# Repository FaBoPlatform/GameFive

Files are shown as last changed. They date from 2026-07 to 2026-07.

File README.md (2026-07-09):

# Game Five

**A handheld game console fully engineered by an AI — Claude "Fable 5"**

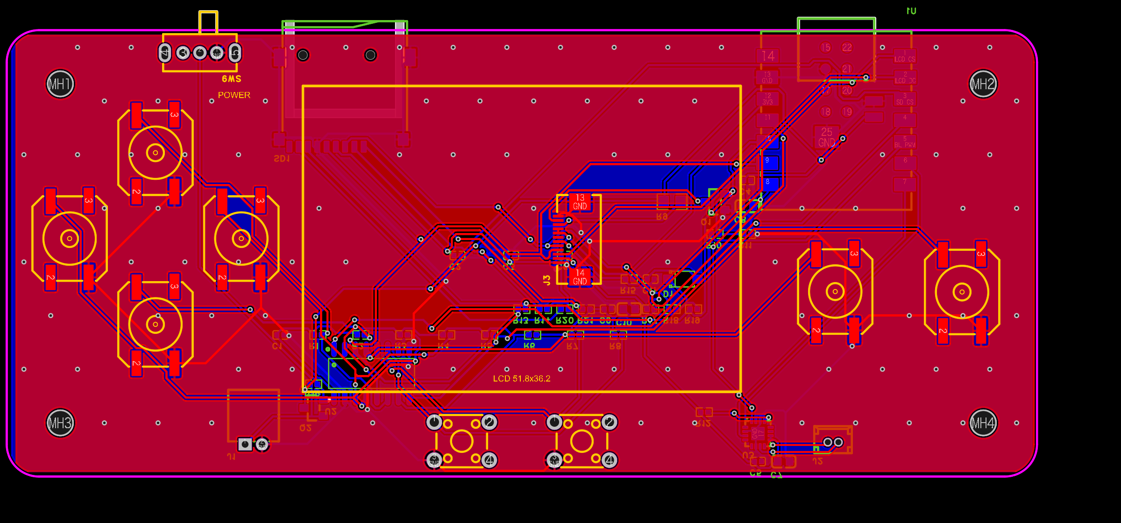
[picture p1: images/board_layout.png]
Game Five PCB (top view)


## About this project

Game Five is an experiment in **end-to-end AI hardware development**. The entire product is designed by **Fable 5** (Anthropic's Claude), directed through natural-language conversation by its human co-designers:

| Deliverable | Developed by Fable 5 | Status |
|---|---|---|
| **Schematic design** | Component selection (all JLCPCB in-stock parts), netlist, power tree, GPIO budgeting via 74HC165 | 🏭 1st prototype in fabrication |
| **PCB layout** | 120 × 61 mm 2-layer board — placement, autorouting, GND pours, stitching vias, DRC clean, fab outputs | 🏭 rev.1 prototype fabricated / rev.2i current (I2S audio restored, battery connector by the D-pad) |
| **Enclosure** | Two-piece 3D-printable case, generated parametrically through the Fusion 360 API | 🚧 In development |
| **Game software** | Board support component + games for ESP32-S3 (display, input, sound drivers) | 🚧 In development — HW test + SNAKE running on the XIAO |

The AI operated the EDA tool (EasyEDA Pro) and the CAD tool (Autodesk Fusion 360) programmatically through their APIs — placing parts, wiring nets, routing, running DRC, exporting Gerbers, and solid-modeling the case — while humans reviewed each iteration and steered the design ("make the D-pad symmetric", "move the display up", "the flat cable folds here").

The hardware itself: a Seeed Studio **XIAO ESP32-S3** driving a 2.0-inch **HS20HS072RX** TFT (ST7789, 240×320, SPI), with GameBoy-style controls and I2S audio.

## Features

- **MCU**: Seeed XIAO ESP32-S3 (Wi-Fi / BLE, USB-C, built-in LiPo charger)
- **Display**: HS20HS072RX 2.0" TFT, 240×320, ST7789, 4-wire SPI (LCSC **C5329582**)
- **Controls**: D-pad + A/B buttons (Panasonic EVQQ1D06M round-plunger tactile switches) + SELECT/START (Omron B3F-1025 through-hole tactile switches — orange round button, crisp 2.55 N click)
- **Audio**: **MAX98357A** I2S mono Class-D amplifier (U3) driving a speaker via a JST 1.25mm 2-pin connector (J2, LCSC **C10819**); SD_MODE pulled up (R12) so the amp is enabled by default, GAIN floated (9 dB)
- **Power**: LiPo battery (JST PH2.0) wired directly to the XIAO BAT± pads — charging is handled by the XIAO's onboard charger
- **Button matrix via 74HC165**: the XIAO exposes only 11 GPIOs, so the 8 buttons are read through a **74HC165** shift register sharing the SPI bus (LCD + buttons + backlight PWM all fit, with I2S pins to spare)
- **PCB**: 120 × 61 mm, 2-layer, ground pours on both sides tied together with ~190 stitching vias, DRC clean
- **Display connector under the panel**: the flat cable folds back at its root (the module's natural fold) and plugs into J3 mounted on the front, underneath the display — a clean rectangular board with no notch and no through-board pass
- **Enclosure**: two-piece 3D-printed case with 1 mm rounded edges — bottom tray with a 10 mm LiPo/speaker cavity and speaker grille, flat solid top cover (print it in clear material so the LCD shows through) with press-through holes for every key (Ø10 mm D-pad/A/B, Ø5 mm SELECT/START); four M2.5 screws pass through the top cover **and the PCB mounting holes** into the bottom bosses, clamping the whole stack together

## Enclosure preview

Two-piece 3D-printable case, solid-modeled parametrically through the Fusion 360 API (1 mm rounded edges, four M2.5 screws clamp top + PCB + bottom as one stack).

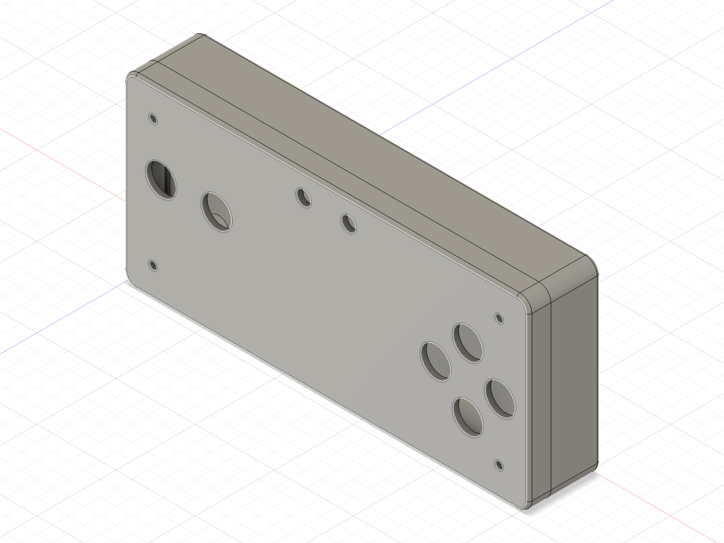
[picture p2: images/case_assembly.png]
Case assembly


| Top cover — Ø10 mm D-pad/A/B holes, Ø5 mm SELECT/START holes, 4× screw through-holes | Bottom tray — 10 mm LiPo/speaker cavity, speaker grille, drop-in USB-C slot, screw bosses |
|---|---|
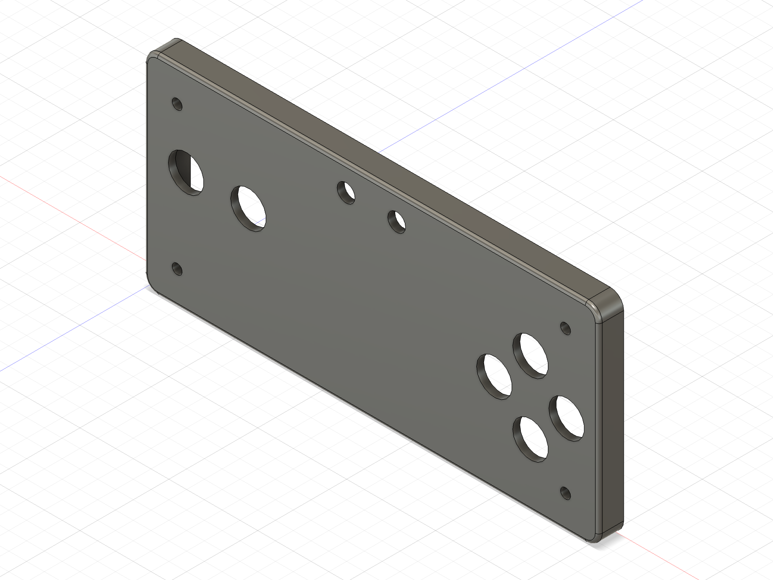
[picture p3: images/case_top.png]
Case top
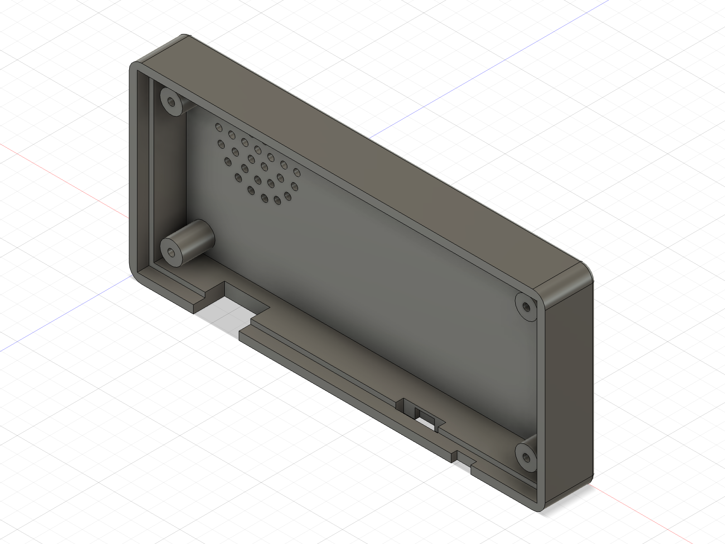
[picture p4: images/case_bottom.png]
Case bottom
|  |  |

## Repository contents

| Path | Contents |
|---|---|
| `fab/GameFive_Gerber.zip` | Gerber files for fabrication (JLCPCB, 2-layer) |
| `fab/GameFive_BOM.xlsx` | Bill of materials with LCSC part numbers (for JLCPCB PCBA) |
| `fab/GameFive_PickAndPlace.xlsx` | Pick-and-place data |
| `case/GameFive_Case_Bottom.stl` / `.step` | Enclosure bottom tray — 10 mm cavity under the PCB for the LiPo + speaker, speaker grille, drop-in USB-C slot |
| `case/GameFive_Case_Top.stl` / `.step` | Enclosure top cover — flat solid deck (clear material recommended), through-holes for all 8 keys |
| `case/case_bottom_fusion360.py` / `case_top_fusion360.py` | Fusion 360 API scripts that regenerate the case parametrically (verification-gated export) |
| `easyeda/GameFive.epro` | **EasyEDA Pro project file** (full schematic + PCB source) — open via File → Open in EasyEDA Pro |
| `firmware/components/gamefive/` | **Board support component** — ST7789 driver, 74HC165 buttons, backlight PWM, pin map, 8×8 font |
| `firmware/hwtest/` | **ESP-IDF hardware bring-up test** — display test patterns + live key test (see its README) |
| `firmware/snake/` | **SNAKE** — the first game (D-pad steer, score, speed-up, high score) |
| `images/` | Board renders |

More games will be added under `firmware/` as development progresses.

## Pin map

| XIAO pin | GPIO | Function |
|---|---|---|
| D0 | GPIO1 | LCD CS |
| D1 | GPIO2 | LCD DC (RS) |
| D2 | GPIO3 | LCD RST |
| D3 | GPIO4 | 74HC165 LATCH (SH/LD#) |
| D4 | GPIO5 | Backlight PWM (SI2302 low-side switch) |
| D5 | GPIO6 | I2S BCLK (MAX98357A) |
| D6 | GPIO43 | I2S LRCLK |
| D7 | GPIO44 | I2S DIN |
| D8 | GPIO7 | SPI SCK (shared by LCD and 74HC165) |
| D9 | GPIO8 | SPI MISO (74HC165 QH) |
| D10 | GPIO9 | SPI MOSI (LCD SDA) |

74HC165 inputs: A=UP, B=DOWN, C=LEFT, D=RIGHT, E=A, F=B, G=START, H=SELECT (10 kΩ pull-ups, active-low).

## Display connection

- The LCD flat cable **folds back at its root** (the module's natural fold, per the datasheet) and plugs into **J3 on the front side, underneath the display** (XKB X05A20L12T, 12-pin 0.5 mm bottom-contact flip connector; mouth toward the module's top edge).
- **J3 is wired in straight pin order** (J3 pin *n* = LCD pin *n*), with the connector rotated 180° to meet the folded tail.
- The silkscreen frame (51.8 × 36.2 mm) on the front marks the display mounting position.
- The display itself (C5329582) is **not included in the BOM** — order it separately.

## Ordering guide (JLCPCB)

1. Upload `fab/GameFive_Gerber.zip` (2-layer, 1.6 mm, any color).
2. For PCBA, upload `GameFive_BOM.xlsx` and `GameFive_PickAndPlace.xlsx`.
3. **U1 (XIAO ESP32-S3) is permanently out of stock at JLC** — either consign the part or mark it DNP and hand-solder it.
4. **J1 (battery connector) and SW7/SW8 (Omron B3F-1025) are through-hole** — not supported by Economic PCBA; use Standard PCBA or hand-solder them.
5. Order the display HS20HS072RX (C5329582) and a LiPo battery separately.
6. 3D-print the case STLs. The case is fastened with four M2.5 screws (~18 mm) that pass through the top cover and the PCB mounting holes into the bottom boss pilot holes — one screw stack holds top, board, and bottom together.

## License

This project is licensed under the **CERN Open Hardware Licence Version 2 – Permissive (CERN-OHL-P-2.0)**.
See [LICENSE](LICENSE) for the full text.

## Credits

- Schematic, PCB layout, enclosure, and game software: **Fable 5** (Claude, Anthropic)
- Co-designed and directed by **Akira & Tom**

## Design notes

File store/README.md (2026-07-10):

# Game Five Store

Games installable over WiFi from the on-device launcher.

## How it works

The launcher (factory partition) fetches `index.txt` from this directory via
GitHub raw, lists the games on screen, and installs the selected one into the
`ota_0` partition (game data goes to the `assets` partition). Hold **B+START
for 2 seconds** inside any game to return to the launcher.

## Index format

One line per game: `id|title|version|bin_url|assets_url|assets_size`
(`assets_url`/`assets_size` empty and 0 when the game has no data file).

## Adding your game

1. Build an ESP-IDF app for the XIAO ESP32-S3 using the shared
   `firmware/launcher/partitions.csv` table (app must fit the 2MB `ota_0`
   slot) and the `gamefive` BSP component.
2. Add the B+START exit combo (see `firmware/snake/main/main.c`).
3. Put the built `.bin` here and add a line to `index.txt` via pull request.
   Games written with AI assistance are very welcome — this whole console is
   an AI-development experiment.

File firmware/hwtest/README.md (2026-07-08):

# Game Five — hardware bring-up test (`hwtest`)

ESP-IDF firmware that exercises the Game Five board: the ST7789 display and
all eight buttons. Flash this first on a freshly assembled prototype.

## What it does

1. **Display test** (runs automatically at boot)
   - backlight PWM fade-in
   - full-screen fills: RED → GREEN → BLUE → WHITE → BLACK (each labeled)
   - 8 color bars, 32-step grayscale gradient, 8 px checkerboard
   - 1 px border + crosshair + colored corner markers (edge alignment check)
   - "GAME FIVE" splash
2. **Key test** (runs forever afterwards)
   - on-screen indicators for UP/DOWN/LEFT/RIGHT/A/B/START/SELECT that
     light up while pressed
   - raw 74HC165 byte shown in hex + binary (for wiring bring-up)
   - every edge logged over USB serial (`idf.py monitor`)
   - hold **SELECT + START for 1.5 s** to re-run the display test

## Build & flash

```bash
. ~/.espressif/v6.0.1/esp-idf/export.sh   # or your ESP-IDF v5.3+/v6 install
cd firmware/hwtest
idf.py set-target esp32s3
idf.py -p /dev/cu.usbmodem*  flash monitor   # XIAO's USB-C (native USB)
```

## Bring-up notes

- **Colors inverted** (RED shows as CYAN)? Set `GF_LCD_INVERT 1` in
  `main/gamefive_pins.h`.
- **Image upside down**? Set `GF_LCD_ROTATE_180 0`.
- **Wrong keys light up**? The raw binary line at the bottom shows the shift
  register byte directly (bit7 = input H = SELECT … bit0 = input A = UP,
  0 = pressed); adjust the mapping in `main/keys.h` to match.
- All pins are defined in one place: `main/gamefive_pins.h`.

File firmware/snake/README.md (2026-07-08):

# Game Five — SNAKE

The first game for Game Five: classic snake on a 30×37 grid.

- **D-pad** — steer
- **START / A** — start, retry, pause (START)
- **SELECT (hold 1.5 s)** — back to the title screen
- Eat food to grow; every food speeds the snake up a little.
- Session high score shown on the HUD and title screen.

## Build & flash

```bash
. ~/.espressif/v6.0.1/esp-idf/export.sh
cd firmware/snake
idf.py set-target esp32s3
idf.py -p /dev/cu.usbmodem* flash monitor
```

Board support (display, buttons, backlight, pins) lives in the shared
component [`firmware/components/gamefive`](../components/gamefive).

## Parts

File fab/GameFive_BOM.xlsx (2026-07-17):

Supplier | Supplier Part | Manufacturer | Manufacturer Part | Value | Footprint | Designator | Comment | Quantity | No.
LCSC | CL05B104KO5NNNC.1 | SAMSUNG(三星) | CL05B104KO5NNNC |  | C0402 | C1,C3,C5,C6 | CL05B104KO5NNNC | 4 | 1
LCSC | CL05A105KA5NQNC.1 | SAMSUNG(三星) | CL05A105KA5NQNC |  | C0402 | C2,C4 | CL05A105KA5NQNC | 2 | 2
LCSC | CL10A106KP8NNNC.1 | SAMSUNG(三星) | CL10A106KP8NNNC |  | C0603 | C7,C8 | CL10A106KP8NNNC | 2 | 3
LCSC | C1525 | SAMSUNG(三星) | CL05B104KO5NNNC |  | C0402 | C9 | CL05B104KO5NNNC | 1 | 4
LCSC | C19702 | SAMSUNG(三星) | CL10A106KP8NNNC |  | C0603 | C10 | CL10A106KP8NNNC | 1 | 5
LCSC | C52923 | SAMSUNG(三星) | CL05A105KA5NQNC |  | C0402 | C11 | CL05A105KA5NQNC | 1 | 6
LCSC | C81598 | ST(先科) | 1N4148W |  | SOD-123F_L2.7-W1.6-LS3.8-RD | D1 | 1N4148W | 1 | 7
LCSC | KH-PH-2P-W.1 | kinghelm(金航标) | KH-PH-2P-W |  | CONN-TH_2P-P2.00_KINGHELM_KH-PH-2P-W | J1 | KH-PH-2P-W | 1 | 8
LCSC | C10819 | BOOMELE | 1.25T-2A |  | CONN-TH_1.25T-1-2A | J2 | 1.25T-2A | 1 | 9
LCSC | X05A20L12T.1 | XKB Connection(中国星坤) | X05A20L12T |  | FFC-SMD_12P-P0.50_X05A20L12T | J3 | X05A20L12T | 1 | 10
LCSC | SI2302_C2938373.1 | GOODWORK(固得沃克) | SI2302 |  | SOT-23_L2.9-W1.3-P1.90-LS2.4-BR | Q1 | SI2302 | 1 | 11
LCSC | C15127 | AOS | AO3401A |  | SOT-23_L2.9-W1.3-P1.90-LS2.4-BR | Q2 | AO3401A | 1 | 12
LCSC | C191123 | PANASONIC | ERJ2RKF1002X |  | R0402 | R1,R2,R3,R4,R5,R6,R7,R8 | ERJ2RKF1002X | 8 | 13
LCSC | 0805W8F220JT5E.1 | UNI-ROYAL(厚声) | 0805W8F220JT5E |  | R0805 | R9 | 0805W8F220JT5E | 1 | 14
LCSC | 0402WGF1000TCE.1 | UNI-ROYAL(厚声) | 0402WGF1000TCE |  | R0402 | R10 | 0402WGF1000TCE | 1 | 15
LCSC | 0402WGF1003TCE.1 | UNI-ROYAL(厚声) | 0402WGF1003TCE |  | R0402 | R11 | 0402WGF1003TCE | 1 | 16
LCSC | C25741 | UNI-ROYAL(厚声) | 0402WGF1003TCE |  | R0402 | R12,R16 | 0402WGF1003TCE | 2 | 17
LCSC | C11702 | UNI-ROYAL(厚声) | 0402WGF1001TCE |  | R0402 | R13 | 0402WGF1001TCE | 1 | 18
LCSC | C191123 | PANASONIC(松下) | ERJ2RKF1002X |  | R0402 | R14,R15,R17,R18,R19,R20,R21 | ERJ2RKF1002X | 7 | 19
LCSC | C91145 | 韩国韩荣 | TF-01A |  | TF-SMD_TF-01A | SD1 | TF-01A | 1 | 20
LCSC | EVQQ1D06M.1 | PANASONIC(松下) | EVQQ1D06M |  | SW-SMD_4P-L10.0-W8.6-P4.50-LS10.0 | SW1,SW2,SW3,SW4,SW5,SW6 | EVQQ1D06M | 6 | 21
LCSC | B3F-1025.1 | OMRON(欧姆龙) | B3F-1025 |  | SW-TH_4P-L6.2-W6.2-P4.50-LS6.5 | SW7,SW8 | B3F-1025 | 2 | 22
LCSC | C2681575 | SHOU HAN | SK12D07VG6 |  | SW-TH_SK12D07VG4 | SW9 | SK12D07VG6 | 1 | 23
LCSC | C9900154951 | JLCPCB | XIAO ESP32S3 |  | COMM-SMD_L21.1-W17.8-P2.54_113991114_XIAO-ESP32-S3 | U1 | XIAO ESP32S3 | 1 | 24
LCSC | SN74HC165DR.1 | TI(德州仪器) | SN74HC165DR |  | SOP-16_L10.0-W3.9-P1.27-LS6.0-BL | U2 | SN74HC165DR | 1 | 25
LCSC | C910544 | Analog Devices | MAX98357AETE+T |  | TQFN-16_L3.0-W3.0-P0.50-BL-EP1.5 | U3 | MAX98357AETE+T | 1 | 26

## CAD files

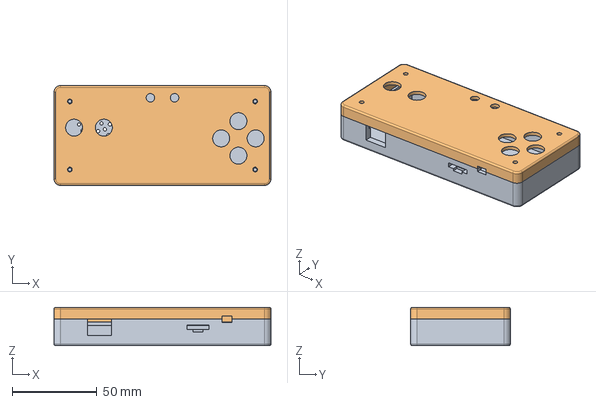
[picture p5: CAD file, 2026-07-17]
case/GameFive_Case_Assembly.step
127.9 x 58.8 x 22.6 mm

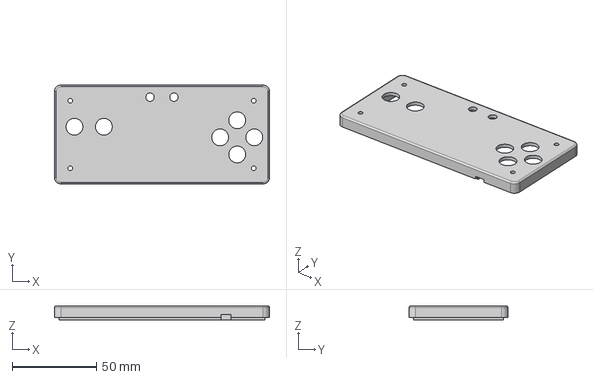
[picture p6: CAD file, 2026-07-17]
case/GameFive_Case_Top.step
127.9 x 58.8 x 8.50 mm

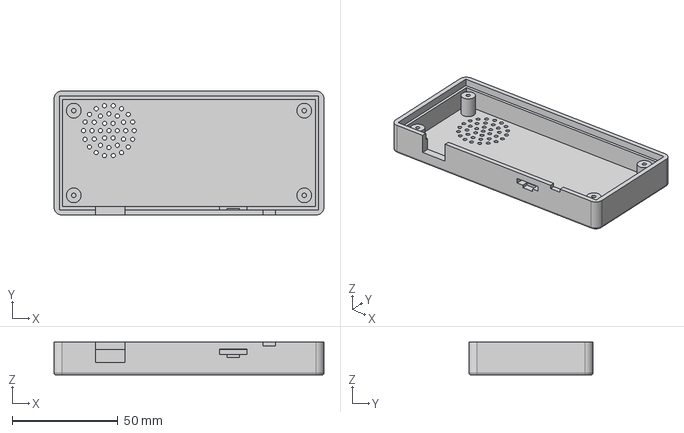
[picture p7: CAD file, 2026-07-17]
case/GameFive_Case_Bottom.step
127.9 x 58.8 x 15.6 mm

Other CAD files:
case/GameFive_Case_Bottom.stl
case/GameFive_Case_Top.stl

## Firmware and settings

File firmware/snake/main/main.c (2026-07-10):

/*
 * Game Five — SNAKE
 *
 * Controls:
 *   D-pad ......... steer
 *   START ......... start game / pause
 *   A ............. start game / restart after game over
 *   SELECT (hold) . back to title
 *
 * SPDX-License-Identifier: CERN-OHL-P-2.0
 */
#include <stdio.h>
#include <string.h>
#include "freertos/FreeRTOS.h"
#include "freertos/task.h"
#include "esp_log.h"
#include "esp_random.h"
#include "esp_system.h"
#include "esp_ota_ops.h"
#include "esp_partition.h"

#include "gamefive_pins.h"
#include "lcd.h"
#include "keys.h"

static const char *TAG = "snake";

/*
 * Old-prototype compatibility (HandyGame rev.0 board): the UP (bit0) and
 * SELECT (bit7) shift-register lines are stuck low on that board, so they
 * are masked out, the A button steers UP, and holding B returns to the
 * title screen. Set to 0 for the Game Five rev.1 board.
 */
#define SNAKE_OLDBOARD_COMPAT 1

#if SNAKE_OLDBOARD_COMPAT
#define KEYS_IGNORE_MASK ((uint8_t)(GF_KEY_UP | GF_KEY_SELECT))
#define TITLE_HOLD_KEY   GF_KEY_B
#else
#define KEYS_IGNORE_MASK ((uint8_t)0)
#define TITLE_HOLD_KEY   GF_KEY_SELECT
#endif

#define W GF_LCD_H_RES            /* 240 */
#define H GF_LCD_V_RES            /* 320 */

#define CELL      8
#define HUD_H     24
#define COLS      (W / CELL)              /* 30 */
#define ROWS      ((H - HUD_H) / CELL)    /* 37 */
#define FIELD_Y   HUD_H
#define MAX_LEN   (COLS * ROWS)

#define TICK_MS          20
#define STEP_START_MS    180
#define STEP_MIN_MS      70
#define STEP_ACCEL_MS    5     /* faster by this much per food */

typedef struct { int8_t x, y; } cell_t;

typedef enum { DIR_UP, DIR_DOWN, DIR_LEFT, DIR_RIGHT } dir_t;

static const int8_t k_dx[] = { 0, 0, -1, 1 };
static const int8_t k_dy[] = { -1, 1, 0, 0 };

/* snake body as a ring buffer of cells; head_i points at the head */
static cell_t s_body[MAX_LEN];
static int s_head_i, s_len;
/* occupancy grid for O(1) self-collision + food placement */
static uint8_t s_occ[COLS][ROWS];

static uint32_t s_score, s_hiscore;

static inline cell_t body_at(int back)   /* back=0 → head */
{
    int i = s_head_i - back;
    while (i < 0) i += MAX_LEN;
    return s_body[i % MAX_LEN];
}

static void cell_fill(cell_t c, uint16_t color)
{
    gf_lcd_fill_rect(c.x * CELL, FIELD_Y + c.y * CELL, CELL, CELL, color);
}

static void draw_snake_cell(cell_t c, bool head)
{
    int x = c.x * CELL, y = FIELD_Y + c.y * CELL;
    gf_lcd_fill_rect(x, y, CELL, CELL, head ? GF_GREEN : GF_RGB(0, 180, 0));
    gf_lcd_fill_rect(x + 1, y + 1, CELL - 2, CELL - 2,
                     head ? GF_RGB(160, 255, 160) : GF_GREEN);
}

static void draw_food(cell_t c)
{
    int x = c.x * CELL, y = FIELD_Y + c.y * CELL;
    gf_lcd_fill_rect(x + 1, y + 1, CELL - 2, CELL - 2, GF_RED);
    gf_lcd_fill_rect(x + 2, y + 2, 2, 2, GF_ORANGE);
}

static void hud_draw(void)
{
    char buf[24];
    gf_lcd_fill_rect(0, 0, W, HUD_H, GF_BLACK);
    gf_lcd_fill_rect(0, HUD_H - 2, W, 2, GF_ORANGE);
    snprintf(buf, sizeof(buf), "SCORE %lu", (unsigned long)s_score);
    gf_lcd_text(6, 4, buf, 2, GF_WHITE, GF_BLACK);
    snprintf(buf, sizeof(buf), "HI %lu", (unsigned long)s_hiscore);
    gf_lcd_text(W - 6 - gf_lcd_text_w(buf, 1), 8, buf, 1, GF_GRAY, GF_BLACK);
}

static cell_t food_place(void)
{
    cell_t c;
    do {
        c.x = (int8_t)(esp_random() % COLS);
        c.y = (int8_t)(esp_random() % ROWS);
    } while (s_occ[c.x][c.y]);
    draw_food(c);
    return c;
}

/* ---- back-to-launcher combo: hold B+START ~2s (works on all boards) ---- */
static void check_exit_combo(uint8_t held)
{
    static int count;
    if ((held & (GF_KEY_B | GF_KEY_START)) == (GF_KEY_B | GF_KEY_START)) {
        if (++count >= 2000 / TICK_MS) {
            const esp_partition_t *factory = esp_partition_find_first(
                ESP_PARTITION_TYPE_APP, ESP_PARTITION_SUBTYPE_APP_FACTORY, NULL);
            if (factory && esp_ota_set_boot_partition(factory) == ESP_OK)
                esp_restart();
        }
    } else {
        count = 0;
    }
}

/* ---- key edge helper ---- */
static uint8_t s_prev_keys;
static uint8_t keys_pressed_edges(uint8_t *held_out)
{
    uint8_t now = gf_keys_read(NULL) & (uint8_t)~KEYS_IGNORE_MASK;
    uint8_t edges = (uint8_t)(now & ~s_prev_keys);
    s_prev_keys = now;
    if (held_out) *held_out = now;
    check_exit_combo(now);
    return edges;
}

/* ---------------------------------------------------------------- title */

static void title_screen(void)
{
    gf_lcd_clear(GF_BLACK);
    gf_lcd_rect(6, 6, W - 12, H - 12, 2, GF_GREEN);
    gf_lcd_text((W - gf_lcd_text_w("SNAKE", 6)) / 2, 80, "SNAKE", 6,
                GF_GREEN, GF_BLACK);

    /* little snake + food doodle */
    for (int i = 0; i < 7; i++) {
        cell_t c = { (int8_t)(8 + i), 18 };
        draw_snake_cell(c, i == 6);
    }
    draw_food((cell_t){ 18, 18 });

    gf_lcd_text((W - gf_lcd_text_w("PRESS START", 2)) / 2, 210,
                "PRESS START", 2, GF_WHITE, GF_BLACK);
#if SNAKE_OLDBOARD_COMPAT
    gf_lcd_text((W - gf_lcd_text_w("A=UP  HOLD B=TITLE", 1)) / 2, 236,
                "A=UP  HOLD B=TITLE", 1, GF_GRAY, GF_BLACK);
#endif
    char buf[24];
    snprintf(buf, sizeof(buf), "HI SCORE %lu", (unsigned long)s_hiscore);
    gf_lcd_text((W - gf_lcd_text_w(buf, 1)) / 2, 250, buf, 1,
                GF_GRAY, GF_BLACK);
    gf_lcd_text((W - gf_lcd_text_w("GAME FIVE", 1)) / 2, 300, "GAME FIVE", 1,
                GF_DKGRAY, GF_BLACK);

    ESP_LOGI(TAG, "title screen");
    for (;;) {
        uint8_t edges = keys_pressed_edges(NULL);
        if (edges & (GF_KEY_START | GF_KEY_A)) return;
        vTaskDelay(pdMS_TO_TICKS(TICK_MS));
    }
}

/* ----------------------------------------------------------------- game */

static void game_over(void)
{
    ESP_LOGI(TAG, "game over, score=%lu", (unsigned long)s_score);
    if (s_score > s_hiscore) s_hiscore = s_score;

    /* flash the snake */
    for (int f = 0; f < 4; f++) {
        for (int i = 0; i < s_len; i++) {
            cell_fill(body_at(i), (f & 1) ? GF_GREEN : GF_RED);
        }
        vTaskDelay(pdMS_TO_TICKS(150));
    }

    int bw = 200, bh = 96;
    int bx = (W - bw) / 2, by = (H - bh) / 2;
    gf_lcd_fill_rect(bx, by, bw, bh, GF_BLACK);
    gf_lcd_rect(bx, by, bw, bh, 2, GF_RED);
    gf_lcd_text(bx + (bw - gf_lcd_text_w("GAME OVER", 2)) / 2, by + 14,
                "GAME OVER", 2, GF_RED, GF_BLACK);
    char buf[24];
    snprintf(buf, sizeof(buf), "SCORE %lu", (unsigned long)s_score);
    gf_lcd_text(bx + (bw - gf_lcd_text_w(buf, 2)) / 2, by + 44, buf, 2,
                GF_WHITE, GF_BLACK);
    gf_lcd_text(bx + (bw - gf_lcd_text_w("A: RETRY", 1)) / 2, by + 76,
                "A: RETRY", 1, GF_GRAY, GF_BLACK);

    for (;;) {
        uint8_t edges = keys_pressed_edges(NULL);
        if (edges & (GF_KEY_A | GF_KEY_START)) return;
        vTaskDelay(pdMS_TO_TICKS(TICK_MS));
    }
}

static void pause_loop(void)
{
    gf_lcd_text((W - gf_lcd_text_w("PAUSE", 3)) / 2, H / 2 - 12, "PAUSE", 3,
                GF_YELLOW, GF_BLACK);
    for (;;) {
        uint8_t edges = keys_pressed_edges(NULL);
        if (edges & GF_KEY_START) return;
        vTaskDelay(pdMS_TO_TICKS(TICK_MS));
    }
}

/* returns when the run ends (game over or SELECT-hold back to title) */
static bool play(void) /* true = back to title requested */
{
    memset(s_occ, 0, sizeof(s_occ));
    s_score = 0;
    s_len = 3;
    s_head_i = s_len - 1;
    dir_t dir = DIR_UP;
    /* two-deep turn queue so quick successive taps (e.g. UP then LEFT
     * within one step) are both honored */
    dir_t dq[2];
    int dq_n = 0;

    gf_lcd_clear(GF_BLACK);
    hud_draw();

    for (int i = 0; i < s_len; i++) {
        cell_t c = { COLS / 2, (int8_t)(ROWS / 2 + (s_len - 1 - i)) };
        s_body[i] = c;
        s_occ[c.x][c.y] = 1;
        draw_snake_cell(c, i == s_len - 1);
    }
    cell_t food = food_place();

    int step_ms = STEP_START_MS;
    int elapsed = 0;
    int sel_hold = 0;

    ESP_LOGI(TAG, "run start");
    for (;;) {
        uint8_t held;
        uint8_t edges = keys_pressed_edges(&held);

        /* queue d-pad edges; each is validated against the direction the
         * snake will have when the turn applies (dir opposites are x^1) */
        static const struct { uint8_t key; dir_t d; } k_map[] = {
            { GF_KEY_UP, DIR_UP }, { GF_KEY_DOWN, DIR_DOWN },
            { GF_KEY_LEFT, DIR_LEFT }, { GF_KEY_RIGHT, DIR_RIGHT },
#if SNAKE_OLDBOARD_COMPAT
            { GF_KEY_A, DIR_UP },  /* A substitutes the dead UP line */
#endif
        };
        for (int k = 0; k < (int)(sizeof(k_map) / sizeof(k_map[0])); k++) {
            if (!(edges & k_map[k].key)) continue;
            dir_t base = dq_n ? dq[dq_n - 1] : dir;
            dir_t d = k_map[k].d;
            if (d != base && d != (base ^ 1) && dq_n < 2) dq[dq_n++] = d;
        }

        if (edges & GF_KEY_START) pause_loop();

        if (held == TITLE_HOLD_KEY) {
            if (++sel_hold >= 1500 / TICK_MS) return true;
        } else {
            sel_hold = 0;
        }

        elapsed += TICK_MS;
        if (elapsed >= step_ms) {
            elapsed = 0;
            if (dq_n > 0) {
                dir = dq[0];
                dq[0] = dq[1];
                dq_n--;
            }

            cell_t head = body_at(0);
            cell_t nh = { (int8_t)(head.x + k_dx[dir]),
                          (int8_t)(head.y + k_dy[dir]) };

            /* wall / self collision */
            if (nh.x < 0 || nh.x >= COLS || nh.y < 0 || nh.y >= ROWS ||
                s_occ[nh.x][nh.y]) {
                game_over();
                return false;
            }

            bool grow = (nh.x == food.x && nh.y == food.y);
            if (!grow) {
                cell_t tail = body_at(s_len - 1);
                s_occ[tail.x][tail.y] = 0;
                cell_fill(tail, GF_BLACK);
            } else {
                s_len++;
                s_score++;
                if (step_ms > STEP_MIN_MS) step_ms -= STEP_ACCEL_MS;
                hud_draw();
            }

            /* old head becomes body */
            draw_snake_cell(head, false);
            s_head_i = (s_head_i + 1) % MAX_LEN;
            s_body[s_head_i] = nh;
            s_occ[nh.x][nh.y] = 1;
            draw_snake_cell(nh, true);

            if (grow) food = food_place();
        }
        vTaskDelay(pdMS_TO_TICKS(TICK_MS));
    }
}

/* ----------------------------------------------------------------- main */

void app_main(void)
{
    ESP_LOGI(TAG, "Game Five SNAKE");
    ESP_ERROR_CHECK(gf_lcd_init());
    ESP_ERROR_CHECK(gf_keys_init());
    for (int p = 0; p <= 100; p += 5) {
        gf_lcd_backlight(p);
        vTaskDelay(pdMS_TO_TICKS(20));
    }

    for (;;) {
        title_screen();
        while (!play()) {
            /* retry until the player asks for the title screen */
        }
    }
}

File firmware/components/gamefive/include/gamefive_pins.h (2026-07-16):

/*
 * Game Five — board pin map (Seeed XIAO ESP32-S3)
 *
 * Matches the Game Five PCB rev.1 (see repository README pin map table).
 * SPDX-License-Identifier: CERN-OHL-P-2.0
 */
#pragma once

/* ---- SPI bus (shared: ST7789 LCD + 74HC165 button shift register) ---- */
#define GF_SPI_HOST        SPI2_HOST
#define GF_PIN_SPI_SCK     7   /* XIAO D8  — LCD SCL + 74HC165 CP  */
#define GF_PIN_SPI_MOSI    9   /* XIAO D10 — LCD SDA               */
#define GF_PIN_SPI_MISO    8   /* XIAO D9  — 74HC165 QH            */

/* ---- ST7789 LCD (HS20HS072RX, 240x320, 4-wire SPI, write-only) ---- */
#define GF_PIN_LCD_CS      1   /* XIAO D0 */
#define GF_PIN_LCD_DC      2   /* XIAO D1 */
#define GF_PIN_LCD_RST     3   /* XIAO D2 */
#define GF_LCD_H_RES       240
#define GF_LCD_V_RES       320
#define GF_LCD_PCLK_HZ     (40 * 1000 * 1000)

/*
 * Screen orientation. Set to 1 if your module shows everything upside down.
 * The current display unit (HS20HS072RX 2025.12 batch, as mounted) needs
 * the 180 flip — confirmed 2026-07-10 on the launcher and DOOM.
 */
#define GF_LCD_ROTATE_180  1

/*
 * Some ST7789 modules (most IPS variants) need color inversion enabled.
 * If RED shows as CYAN during the fill test, flip this to 1.
 * Confirmed 2026-07-09 with a 3-row color-bar test on the HS20HS072RX
 * (2025.12 batch): this panel needs INVON.
 */
#define GF_LCD_INVERT      1

/*
 * HandyGame v1 board: the button column is wired one 74HC165 input off —
 * each button lands on input N+1 (UP→B, ... START→H), input A is stuck low,
 * and SELECT drives that dead input A. Shifting the sample right by one
 * realigns every button with its silkscreen; SELECT then always reads
 * released (7 usable buttons). Set to 0 for correctly-wired boards (rev.2+).
 * Verified 2026-07-10 with the hwtest key screen.
 */
#define GF_KEYS_BIT_SHIFT  1

/* ---- Backlight: SI2302 low-side NMOS, PWM, active high ---- */
#define GF_PIN_LCD_BL      5   /* XIAO D4 */

/* ---- 74HC165 button shift register ---- */
#define GF_PIN_KEYS_LATCH  4   /* XIAO D3 — SH/LD#, pulse LOW to load */

/* ---- I2S audio (MAX98357A) — unused by this test, listed for reference ---- */
#define GF_PIN_I2S_BCLK    6   /* XIAO D5 */
#define GF_PIN_I2S_LRCLK   43  /* XIAO D6 */
#define GF_PIN_I2S_DIN     44  /* XIAO D7 */

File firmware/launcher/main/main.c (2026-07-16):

/*
 * Game Five launcher — resident menu (factory partition).
 * Flow: WiFi creds? -> STA connect -> fetch store index -> menu -> install/boot.
 * No creds (or B on the failure screen) -> SoftAP browser provisioning.
 * Games return here with B+START held (they set the boot partition back).
 */

#include <stdio.h>
#include <string.h>
#include "freertos/FreeRTOS.h"
#include "freertos/task.h"
#include "esp_log.h"
#include "nvs_flash.h"
#include "lcd.h"
#include "keys.h"
#include "wifi_prov.h"
#include "store.h"

static const char *TAG = "launcher";

/* The BSP's GF_KEYS_BIT_SHIFT remap handles the v1 board wiring now;
 * set to 1 only if a board needs extra key masking. */
#define LAUNCHER_OLDBOARD_COMPAT 0

#if LAUNCHER_OLDBOARD_COMPAT
#define KEYS_IGNORE ((uint8_t)(GF_KEY_UP | GF_KEY_SELECT))
#else
#define KEYS_IGNORE ((uint8_t)0)
#endif

#define W 240
#define H 320

#define C_BG     GF_BLACK
#define C_TITLE  GF_RGB(255, 48, 48)
#define C_TEXT   GF_WHITE
#define C_DIM    GF_GRAY
#define C_SEL    GF_RGB(255, 220, 0)
#define C_OK     GF_GREEN

static store_index_t s_index;

/* ---------------- tiny UI helpers ---------------- */

static void ui_clear(void)
{
    gf_lcd_clear(C_BG);
}

static void ui_center(int y, const char *s, int scale, uint16_t fg)
{
    int x = (W - gf_lcd_text_w(s, scale)) / 2;
    gf_lcd_text(x < 0 ? 0 : x, y, s, scale, fg, C_BG);
}

static void ui_header(void)
{
    ui_center(16, "GAME FIVE", 3, C_TITLE);
    ui_center(44, "game store", 1, C_DIM);
}

static void ui_status(const char *line1, const char *line2)
{
    ui_clear();
    ui_header();
    if (line1)
        ui_center(140, line1, 1, C_TEXT);
    if (line2)
        ui_center(160, line2, 1, C_DIM);
}

static uint8_t keys_edges(void)
{
    static uint8_t prev;
    uint8_t now = gf_keys_read(NULL) & (uint8_t)~KEYS_IGNORE;

    /* symmetric toggle: A+B+START ~2s boots the installed game (all
     * launcher screens poll through here at ~50 Hz) */
    static int combo;
    if ((now & (GF_KEY_A | GF_KEY_B | GF_KEY_START))
        == (GF_KEY_A | GF_KEY_B | GF_KEY_START)) {
        if (++combo >= 100 && store_has_game())
            store_boot_game(); /* reboots */
    } else {
        combo = 0;
    }

    uint8_t edges = (uint8_t)(now & ~prev);
    prev = now;
    return edges;
}

static void progress_cb(const char *phase, int done, int total)
{
    static int last_pct = -1;
    char line[40];
    if (total > 0) {
        int pct = (int)((int64_t)done * 100 / total);
        if (pct == last_pct)
            return;
        last_pct = pct;
        snprintf(line, sizeof(line), "%s %d%%", phase, pct);
        int bar = (W - 40) * pct / 100;
        gf_lcd_fill_rect(20, 210, bar, 10, C_OK);
        gf_lcd_rect(20, 210, W - 40, 10, 1, C_DIM);
    } else {
        snprintf(line, sizeof(line), "%s...", phase);
    }
    int tw = gf_lcd_text_w("ASSETS 100%", 1);
    gf_lcd_fill_rect((W - tw) / 2 - 8, 186, tw + 16, 12, C_BG);
    ui_center(186, line, 1, C_TEXT);
}

/* ---------------- screens ---------------- */

static void screen_provisioning(void)
{
    ui_clear();
    ui_header();
    ui_center(90, "WiFi SETUP", 2, C_SEL);
    gf_lcd_text(12, 130, "1. On your phone, join", 1, C_TEXT, C_BG);
    gf_lcd_text(24, 146, "WiFi: " GF_PROV_AP_SSID, 1, C_OK, C_BG);
    gf_lcd_text(12, 170, "2. Open in a browser:", 1, C_TEXT, C_BG);
    gf_lcd_text(24, 186, GF_PROV_URL, 1, C_OK, C_BG);
    gf_lcd_text(12, 210, "3. Enter your WiFi and", 1, C_TEXT, C_BG);
    gf_lcd_text(24, 226, "save. I will reboot.", 1, C_TEXT, C_BG);
    if (store_has_game())
        ui_center(260, "START: back to game", 1, C_SEL);

    wifi_provisioning_start();

    /* START escapes to the installed game. Two live LCD lines: what the
     * user does in the browser (over WebSocket) and the connect state.
     * On CONNECTED, reboot into the launcher's normal flow after a beat. */
    char last_status[48] = "", last_act[48] = "";
    int ok_ticks = 0;
    for (;;) {
        uint8_t e = keys_edges();
        if ((e & GF_KEY_START) && store_has_game())
            store_boot_game(); /* reboots */

        const char *act = wifi_prov_activity();
        if (strcmp(act, last_act) != 0) {
            strlcpy(last_act, act, sizeof(last_act));
            gf_lcd_fill_rect(0, 270, W, 14, C_BG);
            ui_center(270, act, 1, C_TEXT);
        }
        const char *st = wifi_prov_status();
        if (strcmp(st, last_status) != 0) {
            strlcpy(last_status, st, sizeof(last_status));
            gf_lcd_fill_rect(0, 286, W, 14, C_BG);
            ui_center(286, st, 1,
                      strstr(st, "FAILED") ? C_TITLE : C_OK);
        }
        if (strncmp(st, "CONNECTED", 9) == 0 && ++ok_ticks >= 125)
            esp_restart(); /* ~2.5s: let the phone see the success page */
        vTaskDelay(pdMS_TO_TICKS(20));
    }
}

static void screen_wifi_failed(const char *ssid)
{
    ui_clear();
    ui_header();
    ui_center(120, "WiFi FAILED", 2, C_TITLE);
    ui_center(156, ssid, 1, C_DIM);
    ui_center(172, wifi_fail_hint(), 1, C_SEL);
    ui_center(200, "A: retry   B: WiFi setup", 1, C_TEXT);
    for (;;) {
        uint8_t e = keys_edges();
        if (e & GF_KEY_A)
            esp_restart();
        if (e & GF_KEY_B) {
            wifi_creds_clear();
            esp_restart(); /* boots into provisioning */
        }
        vTaskDelay(pdMS_TO_TICKS(20));
    }
}

static void menu_draw(int sel)
{
    ui_clear();
    ui_header();
    for (int i = 0; i < s_index.count; i++) {
        store_game_t *g = &s_index.games[i];
        int y = 80 + i * 26;
        uint16_t fg = (i == sel) ? C_SEL : C_TEXT;
        gf_lcd_text(8, y, (i == sel) ? ">" : " ", 2, C_SEL, C_BG);
        gf_lcd_text(28, y, g->title, 2, fg, C_BG);
        int st = store_installed_state(g);
        if (st == 2)
            gf_lcd_text(W - 30, y + 4, "OK", 1, C_OK, C_BG);
        else if (st == 1)
            gf_lcd_text(W - 36, y + 4, "UPD", 1, C_SEL, C_BG);
    }
    int y = 80 + s_index.count * 26;
    gf_lcd_text(8, y, (sel == s_index.count) ? ">" : " ", 2, C_SEL, C_BG);
    gf_lcd_text(28, y, "WIFI SETUP", 2,
                (sel == s_index.count) ? C_SEL : C_DIM, C_BG);

    ui_center(H - 24, "L/R/DOWN: move   A: play", 1, C_DIM);
}
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

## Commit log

2026-07-02 Game Five: XIAO ESP32-S3 handheld game console — PCB fab data, 3D-printable case, CERN-OHL-P-2.0
    [GameFive_BOM.xlsx, GameFive_Case_Assembly.step, GameFive_Case_Bottom.stl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]
2026-07-02 Add EasyEDA Pro project source (.epro); refresh Gerber with fixed silkscreen credit
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2026-07-08 Screen native orientation (no 180 flip), debounced key reads, snake turn queue
    - GF_LCD_ROTATE_180 -> 0: panel confirmed upright as mounted
    - keys: accept a change only after two consecutive identical samples
    (~40 ms at 50 Hz) to filter switch bounce and floating-pin noise
    - snake: two-deep direction queue validated against the pending
    direction, so quick successive taps both register
    [gamefive_pins.h, keys.c, main.c]
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2026-07-08 snake: old-prototype compatibility mode (SNAKE_OLDBOARD_COMPAT)
    The HandyGame rev.0 board has UP (bit0) and SELECT (bit7) shift-register
    lines stuck low; mask them out, steer UP with the A button, return to
    title by holding B. Set the flag to 0 for the Game Five rev.1 board.
    [main.c]
2026-07-08 PCB rev.2: 120x61mm, square notch, front-mounted display connector, gold round-button SELECT/START
    - board height 85 -> 61 mm; controls re-centered (D-pad left, A/B right,
    SELECT/START below A/B); mounting holes, battery/speaker connectors and
    bottom passives repacked; DRC clean, ~190 stitching vias re-placed
    - FPC notch is now square and shallow (26 x 2.5 mm); J3 moved to the FRONT
    (mouth toward the display) so the flat cable inserts straight with no
    fold and no through-board pass -> straight 1:1 pin mapping restored
    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
    [GameFive_BOM.xlsx, GameFive_PickAndPlace.xlsx]
2026-07-08 PCB rev.2b: plain rectangular board (notch removed), J3 under the display
    - J3 rotated 180 and moved down under the panel: the tail folds back at
    its root (the module's natural fold) and plugs in beneath the display
    - A/B lowered; SELECT/START moved above them (top-right gold buttons)
    - rerouted, 191 stitching vias, DRC clean; fab + EasyEDA source updated
    [GameFive_PickAndPlace.xlsx]
2026-07-08 PCB rev.2c: drop the speaker circuit for now; display connector lower
    - removed U3 (MAX98357A), J2 (speaker JST) and R12 (SD_MODE pull-up);
    XIAO I2S pins stay reserved for a future audio add-on
    - J3 moved further down under the panel (contact row ~15 mm below the
    module top edge, within the folded tail's reach)
    - rerouted, 194 stitching vias, DRC clean; fab/BOM/PnP/EasyEDA source updated
    [GameFive_BOM.xlsx, GameFive_PickAndPlace.xlsx]
2026-07-08 PCB rev.2d: display connector top edge at 18.5 mm from the board top
    J3 moved to (2362,-841) so the connector housing's upper (mouth) edge
    sits 18.5 mm below the top board edge, matching the measured fold
    position of the display's flat cable. Rerouted, 201 stitching vias,
    DRC clean; fab and EasyEDA source regenerated.
    [GameFive_PickAndPlace.xlsx]
2026-07-08 PCB rev.2e: SELECT/START to bottom-center with taller switches; A/B lowered
    - SELECT/START moved below the display (GameBoy-style pair) and switched
    to XKB TS-1187A-C-H-B (C528025) with a 4 mm gold round button
    - display frame raised (top edge 3 mm from board top) to make room;
    J3 stays at the user-specified absolute 18.5 mm from the board top
    - A/B lowered to y=-1450; labels repositioned
    - rerouted, 208 stitching vias, DRC clean; fab/BOM/PnP/EasyEDA source updated
    [GameFive_BOM.xlsx, GameFive_PickAndPlace.xlsx]
2026-07-08 PCB rev.2f: Omron B3F-1025 SELECT/START (crisp THT click), XIAO raised
    - SELECT/START switched to Omron B3F-1025 (C726009): 6x6 through-hole,
    orange round button, 2.55 N crisp tactile click, wired diagonally
    - display frame raised to 1.5 mm from the top edge and J3 moved with it,
    preserving the user-measured connector-to-module relation (housing top
    edge 10.4 mm below the module top edge); bottom strip now fits the 6 mm
    switch bodies with clean outline clearances
    - XIAO moved up ~5 mm (USB-C stays on the right edge); battery connector
    relocated to clear the new through-hole pins
    - rerouted, 221 stitching vias, DRC clean; fab/BOM/PnP/EasyEDA source updated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
    [GameFive_BOM.xlsx, GameFive_PickAndPlace.xlsx]
2026-07-08 PCB rev.2g: display connector at user-verified position (2360,-890)
    J3 placed against the physical display's folded-cable landing point
    (hand-adjusted in EasyEDA); rerouted, 221 stitching vias, DRC clean;
    fab and EasyEDA source regenerated.
    [GameFive_PickAndPlace.xlsx]
2026-07-08 PCB rev.2h: battery connector J1 moved toward D-pad (1700,-2000 -> 1300,-2000)
    Full re-route after move (371 tracks, 157 stitching vias, DRC 0).
    Gerber/PnP/epro regenerated; BOM unchanged.
    [GameFive_PickAndPlace.xlsx]
2026-07-09 PCB rev.2i: restore speaker audio (MAX98357A + JST 1.25mm C10819)
    - Re-add U3 MAX98357A I2S amp, J2 speaker connector (1.25T-2A / C10819),
    R12 SD_MODE pullup; I2S BCLK/LRCLK/DIN now driven (were reserved).
    - Full re-route (464 tracks, 171 stitching vias), GND pour rebuilt, DRC 0.
    - Netlist verified: I2S_DIN/BCLK/LRCLK x2, SPK_P/SPK_N/SPK_SD x2.
    - Gerber + .epro regenerated; BOM/PnP patched with the 3 new parts
    (EasyEDA export API wedged this session; Gerber is fresh authoritative).
    [GameFive_BOM.xlsx, GameFive_PickAndPlace.xlsx]
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2026-07-09 case: GameFive bottom tray v1 (Fusion 360 scripted)
    - 126 x 67 x 20.6 mm; 15 mm cavity under the PCB for the speaker and
    LiPo battery (user spec), 2 mm floor, 2.5 mm walls, R3.81 corners.
    - PCB sits on a 1.5 mm perimeter ledge + four 7 mm corner bosses
    (M2.5 self-tap pilots) matching the board's mounting holes.
    - USB-C drop-in slot in the right wall (XIAO on the board's back side).
    - Verified: single shell (lumps=1), 8 pointContainment probes, bbox in mm.
    - case_bottom_fusion360.py regenerates the part via the Fusion 360 API.
    - Old Case_Top/Assembly files predate rev.2 and will be replaced when
    the matching top lid is designed.
    [GameFive_Case_Bottom.step, GameFive_Case_Bottom.stl]
2026-07-09 case: speaker grille in bottom tray floor
    37x D2 holes in concentric rings (D28 pattern) centered at case
    (100, 40) mm - under the speaker bay next to J2. Regenerated with
    full verification (single shell, 10 containment probes).
    [GameFive_Case_Bottom.step, GameFive_Case_Bottom.stl]
2026-07-09 case: cut the USB-C slot fully through the wall and ledge
    The previous slot left a 0.5 mm membrane on the ledge side (slot cut
    started at x122.5 while the ledge extends to x122). Slot now cuts from
    x119 through the outer wall, verified by two new containment probes
    (ledge zone and wall zone both empty).
    [GameFive_Case_Bottom.step, GameFive_Case_Bottom.stl]
2026-07-09 case: under-PCB cavity 15mm -> 10mm (user spec)
    Overall height 20.6 -> 15.6mm; USB slot bottom now parametric
    (6mm below PCB underside); bosses/pilots follow. All 12 verification
    probes pass, single shell.
    [GameFive_Case_Bottom.step, GameFive_Case_Bottom.stl]
2026-07-09 case: GameFive top cover v1 (raised display mound + key holes)
    - Gently raised display mound: +3mm plateau with 7-8mm slope bands on
    all four sides (tilted-box cuts), covering the LCD active area with
    margin; ends 1mm clear of the SELECT/START holes.
    - Through-holes over all 8 keys: D-pad/A/B D8 (EVQQ round buttons),
    SELECT/START D7 (B3F plungers reach into the holes).
    - 2.5mm skirt + 2mm deck (inner ceiling clears switch bodies), alignment
    tongue ring into the bottom pocket (open across the SELECT/START span),
    R3.81 corners to match the bottom tray.
    - Verified: single shell, 18 containment probes (incl. deck integrity
    around the mound after fixing a tilted-cut axis/length bug).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
    [GameFive_Case_Assembly.step, GameFive_Case_Top.step, GameFive_Case_Top.stl]
2026-07-09 Case for rev.2 board: 10 mm LiPo/speaker cavity bottom + press-through-hole top
    - bottom tray (126 x 67 x 15.6 mm): 2 mm floor, 10 mm cavity under the
    PCB for the LiPo battery and speaker, speaker grille in the floor,
    corner screw bosses (M2.5), drop-in USB-C slot in the right wall
    - top cover: raised display mound with sloped sides, through-holes for
    all 8 keys verified against the board coordinates (D-pad/A/B 8 mm for
    the 6.2 mm EVQQ1 plungers, SELECT/START widened to 9.5 mm so the
    deeper-sitting Omron B3F buttons are comfortably pressable),
    alignment tongue, M2.5 clearance holes
    - every cut verified by pointContainment and lumps==1 before export
    (scripts refuse to export oth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
    [GameFive_Case_Bottom.step, GameFive_Case_Top.step, GameFive_Case_Top.stl]
2026-07-09 Case: mirror left-right, 7 mm interior headroom, smaller SELECT/START holes
    - whole case mirrored about the x center so the printed parts match the
    physical board orientation (USB slot now in the left wall of the tray,
    D-pad holes right / A-B left on the cover as printed)
    - top interior raised to 7 mm above the PCB (deck ceiling 5 mm + 2 mm rim)
    so the 6.5 mm switches have clearance; alignment tongue extended to
    keep the body a single shell (the gated export caught the split)
    - SELECT/START holes reduced from 9.5 to 8 mm
    - bottom's USB slot remains open through the top edge (drop-in), with an
    explicit open-at-top verification probe added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
    [GameFive_Case_Bottom.step, GameFive_Case_Bottom.stl, GameFive_Case_Top.step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]
2026-07-09 Case: assembled STEP regenerated from the saved Fusion document (gamefive)
    The Fusion cloud document 'gamefive' now holds the final mirrored case
    (bottom tray + top cover mated at the seam) as the editable master.
    [GameFive_Case_Assembly.step]
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2026-07-09 Case: 10mm D-pad/A/B holes, 5mm SELECT/START, M2.5 through-screw fastening, R1 rounded edges
    - D-pad/A/B button holes enlarged to 10mm (EVQQ1 plunger 6.2mm)
    - SELECT/START holes reduced to 5mm (B3F-1025 plunger 3.5mm)
    - Top cover gains 4x 2.8mm clearance holes at the PCB mounting holes:
    M2.5 screws now clamp top cover + PCB + bottom bosses as one stack
    - 1mm rounded edges on the case top/bottom outer perimeters
    [GameFive_Case_Assembly.step, GameFive_Case_Bottom.step, GameFive_Case_Bottom.stl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]
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2026-07-13 Key-read guard (raw 0x00 = no input), launcher provisioning hardening
    BSP: gf_keys_read treats a 0x00 shift-register byte (all 8 keys 'pressed'
    at once = register not driving MISO) as no input — phantom B+START was
    erasing otadata via the exit combo 2s after every DOOM boot, bouncing the
    device back to the launcher.
    Launcher: captive-portal probe answers + wildcard routes + request logs,
    STA disconnect reason shown on the failure screen (2.4GHz-only hint),
    WiFi TX power capped and backlight lowered for the v1 board's marginal
    power, NVS-based provisioning path documented (nvs_partition_gen).
    store/: bins rebuilt with the guard.
    [keys.c, main.c]
2026-07-15 DOOM sound fix + OPL2 music: 32 kHz I2S (MAX98357A rejects 11.025k), prboom-plus OPL synth
    - I2S LRCLK 11025 -> 32000 Hz: the MAX98357A clock monitor mutes at
    unsupported rates (11.025/22.05 kHz are not in its list) - this was
    why the first sound revision was silent. SFX steppers resample.
    - New components/oplmusic: prboom-plus MUSIC sources (GPL-2.0, headers
    intact) - DBOPL OPL2 emulator, MUS->MIDI, midifile, oplplayer.
    Compat contained in build flags + gf_compat.h/SDL_stdinc.h shims.
    - i_sound.c: mus_card=1, MUS->MIDI on register, OPL rendered in the
    core-1 mixer task under a mutex; music volume mapped 0..15.
    - Verified on hardware via serial: OPL2 at 32 kHz, title+demo music
    p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
    [i_sound.c]
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2026-07-16 v1 board key wiring remap + 7-button DOOM controls
    BSP: GF_KEYS_BIT_SHIFT — the v1 board's button column is wired one 74HC165
    input off (every button lands on input N+1; input A is stuck low and the
    SELECT button drives it = electrically dead). A one-bit right shift of the
    sample realigns all buttons with the silkscreen; SELECT reads released.
    Measured with the hwtest key screen.
    DOOM controls (7 buttons): up/down move, left/right strafe, B+left/right
    turn, B tap = menu (A confirm / B back inside), A fire, START use,
    A+B+START 2s = back to launcher. Portrait 180-flip option added earlier.
    [gamefive_pins.h, keys.c]
2026-07-16 BSP: GF_LCD_ROTATE_180=1 for this display unit; drop DOOM's app-level flip
    The 180 base orientation now lives in the BSP so every app (launcher,
    doom, snake, hwtest) renders upright without per-app flips.
    [gamefive_pins.h]
2026-07-16 WiFi Setup: 2.4GHz-only SSID dropdown + live connect test with error feedback
    - SSID field is now a <select> filled only from the device's own scan
    (the ESP32-S3 radio is 2.4GHz-only, so 5GHz networks cannot appear),
    with a Rescan link.
    - Submitting runs a connect test while the SoftAP stays up (APSTA): the
    browser polls /status and shows Connecting / Connected (save+reboot) /
    Connection failed with the exact reason (wrong password / not found).
    Credentials are saved only on success.
    - The LCD mirrors the state (connecting / FAILED reason) on a status line.
    [main.c]
2026-07-16 WiFi Setup: 15dBm TX power + WebSocket live link browser<->LCD
    - TX power set to 15dBm (esp_wifi_set_max_tx_power(60)) per
    qiita.com/Kurogara/items/afb092bf7fc7a060c0d8 — the 19.5dBm default
    is noisy; 8.5dBm was tighter than needed.
    - /ws WebSocket endpoint (CONFIG_HTTPD_WS_SUPPORT): the setup page
    streams user actions in real time to the console LCD — phone linked,
    selected network, password length (masked) — and the device pushes
    connect state (connecting/ok/fail+reason) back to the page, replacing
    the meta-refresh polling when WS is available (POST /status flow kept
    as fallback). Reboot-on-success moved to the LCD loop.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
    [main.c]
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2026-07-16 DOOM: START long-press (0.6s) opens the menu — fallback for the broken SELECT line
2026-07-16 Store OTA updates: version-aware UPD marker, assets keyed by size
    - Launcher menu shows UPD (yellow) when the installed game has a newer
    version in the store; A re-downloads it OTA. OK (green) = current.
    - Assets identity is now (game id, size) so a game-binary-only update
    skips the multi-MB WAD re-download.
    - store/index.txt bumped to 1.1 (latest doom/snake bins).
    [main.c]
2026-07-17 Board rev.2k: microSD + P-FET power switch, wide-format 121.9x52.8mm
    - microSD slot (TF-01A) top edge, card ejects upward next to power switch
    - Power: AO3401A high-side P-FET; slide switch now carries only gate
    current (LCSC SK12D07VG6 is 0.3A-rated, direct battery path exceeded it)
    - SD bus fixes from adversarial review: 10k pullups on CMD/DAT0-3 + LCD_CS,
    1k series on 74HC165 QH (shared MISO), SER tied to 3V3
    - LCD reset freed for SD_CS (GPIO3): RC power-on reset (10k+1uF) +
    1N4148W fast-discharge diode
    - Board 120x61 -> 121.9x52.8mm; display/keys respaced, J3 at 23mm from
    display fold edge, START/SELECT symmetric about board center
    - DRC 0, 91 GND stitching vias, fab outputs + ep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
    [GameFive_BOM.xlsx, GameFive_PickAndPlace.xlsx]
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2026-07-17 Round display: GC9B72 2.1" 360x360 bring-up test + experimental DOOM port
    - firmware/roundtest: standalone GC9B72 test (color fills / bars / gradient /
    ring edge-check). Round module plugs into J3 reversed; its control pins
    land on repurposed nets, remapped via the GPIO matrix (SDA=IO2 CS=IO9
    DC=IO3 RST=IO1, SCK shared IO7) - no hardware changes needed
    - Init sequence from xboot/xstar fb-gc9b72.c (verified against the
    MaliosDark/Arduino_GC9B72 port): FE/EF unlock, COLMOD 0x05, no INVON
    - firmware/doom: DOOM_ROUND_DISPLAY=1 renders 320x240 downscaled x0.9 to
    288x216, centered so the frame corners exactly touch the circular edge
    (nothing cropped incl. status bar); shared SPI bus ke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
    [main.c, round_lcd.c]
